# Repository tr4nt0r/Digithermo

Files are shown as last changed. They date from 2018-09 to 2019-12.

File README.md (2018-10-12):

# Digithermo
Digital Thermometer
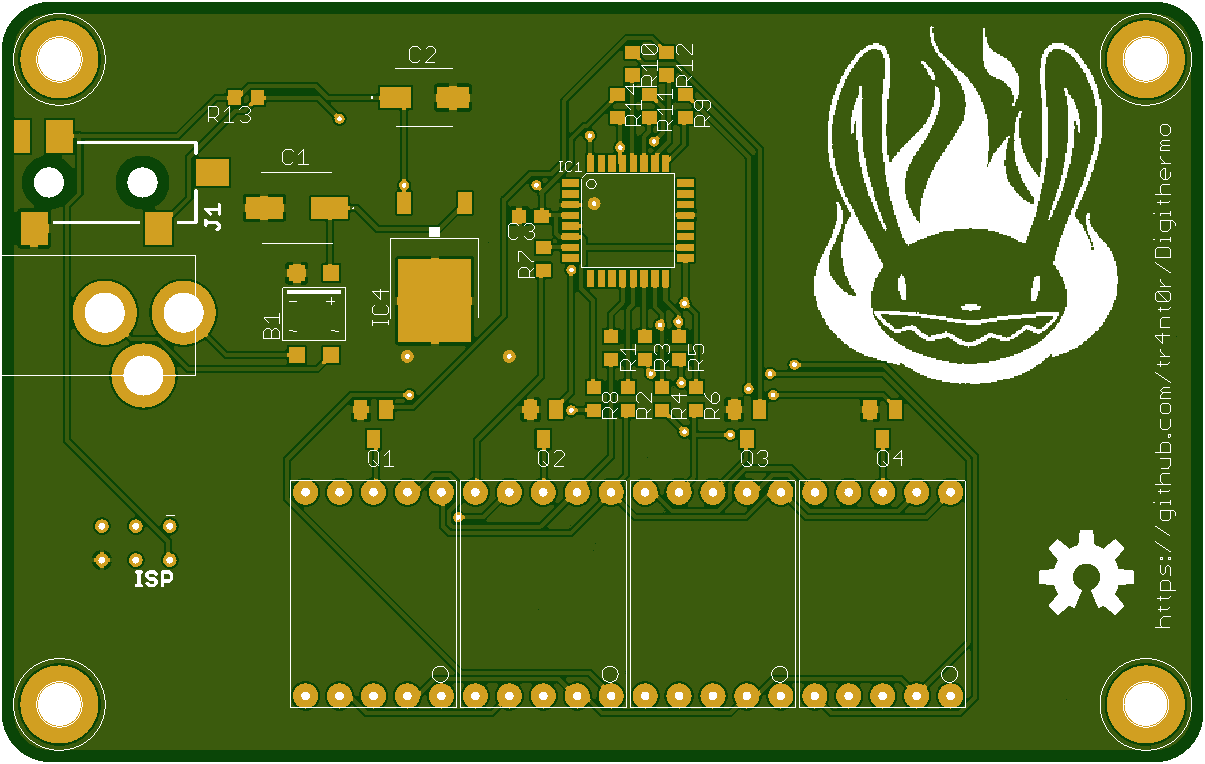
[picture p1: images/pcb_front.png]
PCB Front


# BOM

Qty | Parts              | Value    | Device          | Package      | Description      |Vendor       |
----|--------------------|----------|-----------------|--------------|------------------|-------------|
1   |B1                  |MB6S      |Rectifier        |SOIC-4        |Bridge Rectifier  |[AliExpress](https://www.aliexpress.com/item/-/32838702658.html?spm=a2g0s.8937460.0.0.4f812e0eONVXqt)
1   |C1                  |100µ/16V  |Elko             |SMD 6.3x5.4mm |e.g. EEEFT1C101AR |[AliExpress](https://www.aliexpress.com/item/-/32911815415.html?spm=a2g0s.8937460.0.0.4f812e0eONVXqt)
1   |C2                  |10µ/16V   |Elko             |SMD 5x4mm     |e.g. EEEFK1C100AR |[AliExpress](https://www.aliexpress.com/item/Free-shiping-20pcs-16V-10UF-SMD-4x5mm-chip-Aluminum-Electrolytic-Capacitor/1342839445.html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)
1   |C3                  |100n      |Capacitor        |0603          |
1   |IC1                 |MEGA8     |Microcontroller  |TQFP32        |Atmel ATmega8A-AU|[AliExpress](https://www.aliexpress.com/item/-/32883046023.html?spm=a2g0s.8937460.0.0.4f812e0eONVXqt)
1   |IC4                 |7805      |Voltage regulator|DPAK/TO252    |L78M05CDT        |[AliExpress](https://www.aliexpress.com/item/20pcs-lot-New-78M05-TO252-7805-750mA-L78M05CDT-Three-terminal-voltage-regulator-tube/32818562902.html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)
4   |Q1,Q2,Q3,Q4         |BC847     |Transistor       |SOT23         |NPN Transistor   |[AliExpress](https://www.aliexpress.com/item/100pcs-BC847C-BC847-SOT-23-NPN-smd-transistor/32364894157.html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)
7   |R1,R2,R3,R4,R5,R6,R7|220       |Resistor         |0603          |
1   |R8                  |390       |Resistor         |0603          |
5   |R9,R10,R11,R12,R13  |4,7k      |Resistor         |0603          |
1   |R14                 |10k       |Resistor         |0603          |
4   |U1,U2,U3,U4         |          |7-Segment Display|              |0,56", Common Cathode|[AliExpress](https://www.aliexpress.com/item/-/32876326696.html?spm=a2g0s.8937460.0.0.4f812e0eONVXqt)
1   |J1                  |          |3.5mm Audio Jack |SMD           |e.g. PJ-328          |[AliExpress](https://www.aliexpress.com/item/10PCS-3-5mm-Female-Audio-Connector-5-Pin-SMT-SMD-Headphone-Jack-Socket-PJ-328/32828776775.html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)
1   |                    |          |3.5mm Audio Plug |              |                     |[AliExpress](https://de.aliexpress.com/item/10Pcs-lot-Plastic-metal-3-5mm-Male-Plug-Jack-Adapter-dual-channel-Audio-Connector-Male-Jack/32890263251.html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)
1   |J2                  |          |DC Jack 2.1mm    |              |                     |[AliExpress](https://www.aliexpress.com/item/-/32902679494.html?spm=a2g0s.8937460.0.0.4f812e0eONVXqt)
1   |                    |DS18b20   |Temperaturfühler |              |                     |[AliExpress](https://www.aliexpress.com/item/Stainless-steel-package-Waterproof-DS18b20-temperature-probe-temperature-sensor-18B20-For-Arduino/32236998050.html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)

# Schematic

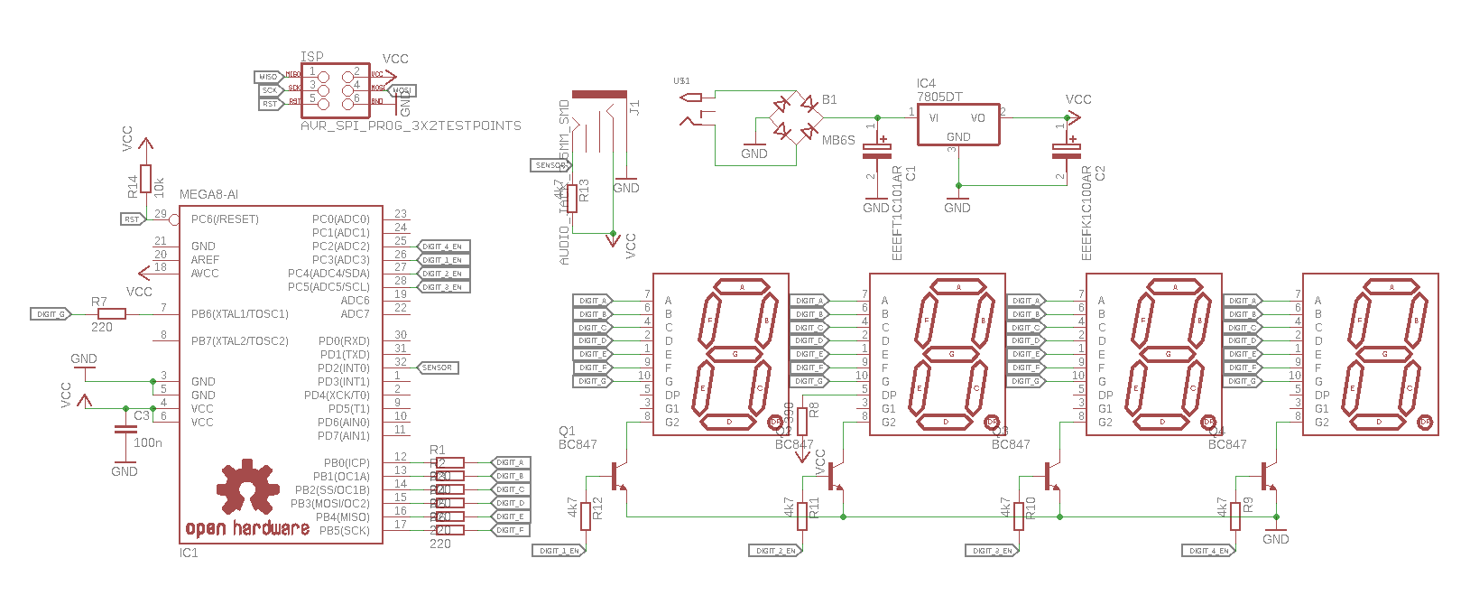
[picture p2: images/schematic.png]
Schematic


# Anschlüsse Temperaturfühler

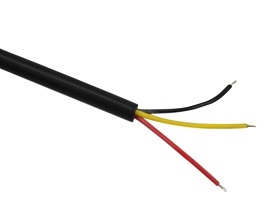
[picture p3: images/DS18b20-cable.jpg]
Anschlüsse Temeperaturfühler


Rot: VCC  
Schwarz: GND  
Gelb: DATA  

# Bilder

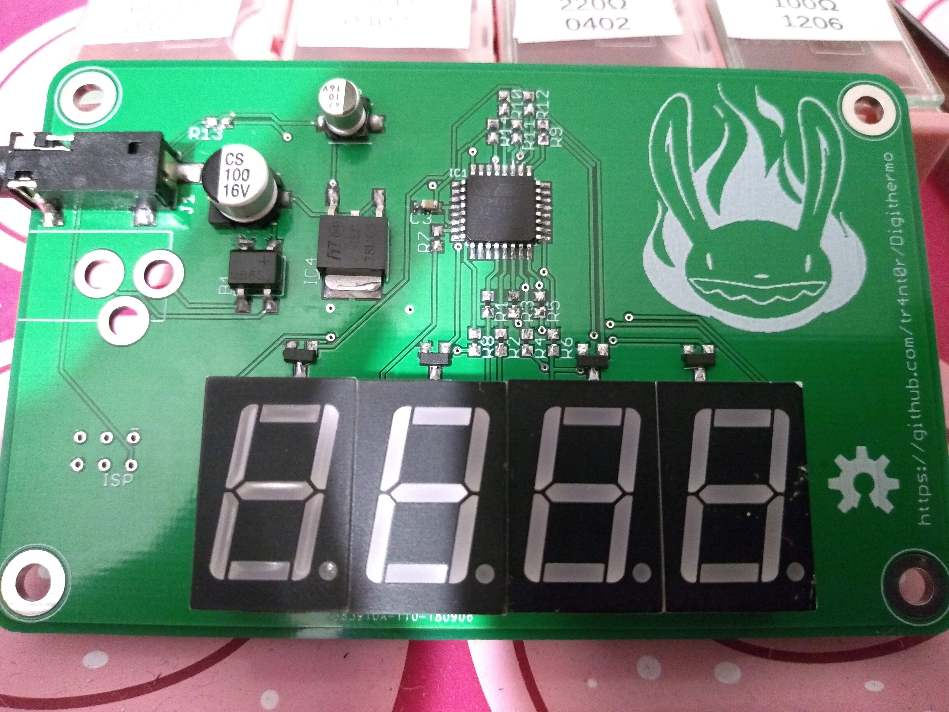
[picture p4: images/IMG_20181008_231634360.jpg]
Bild


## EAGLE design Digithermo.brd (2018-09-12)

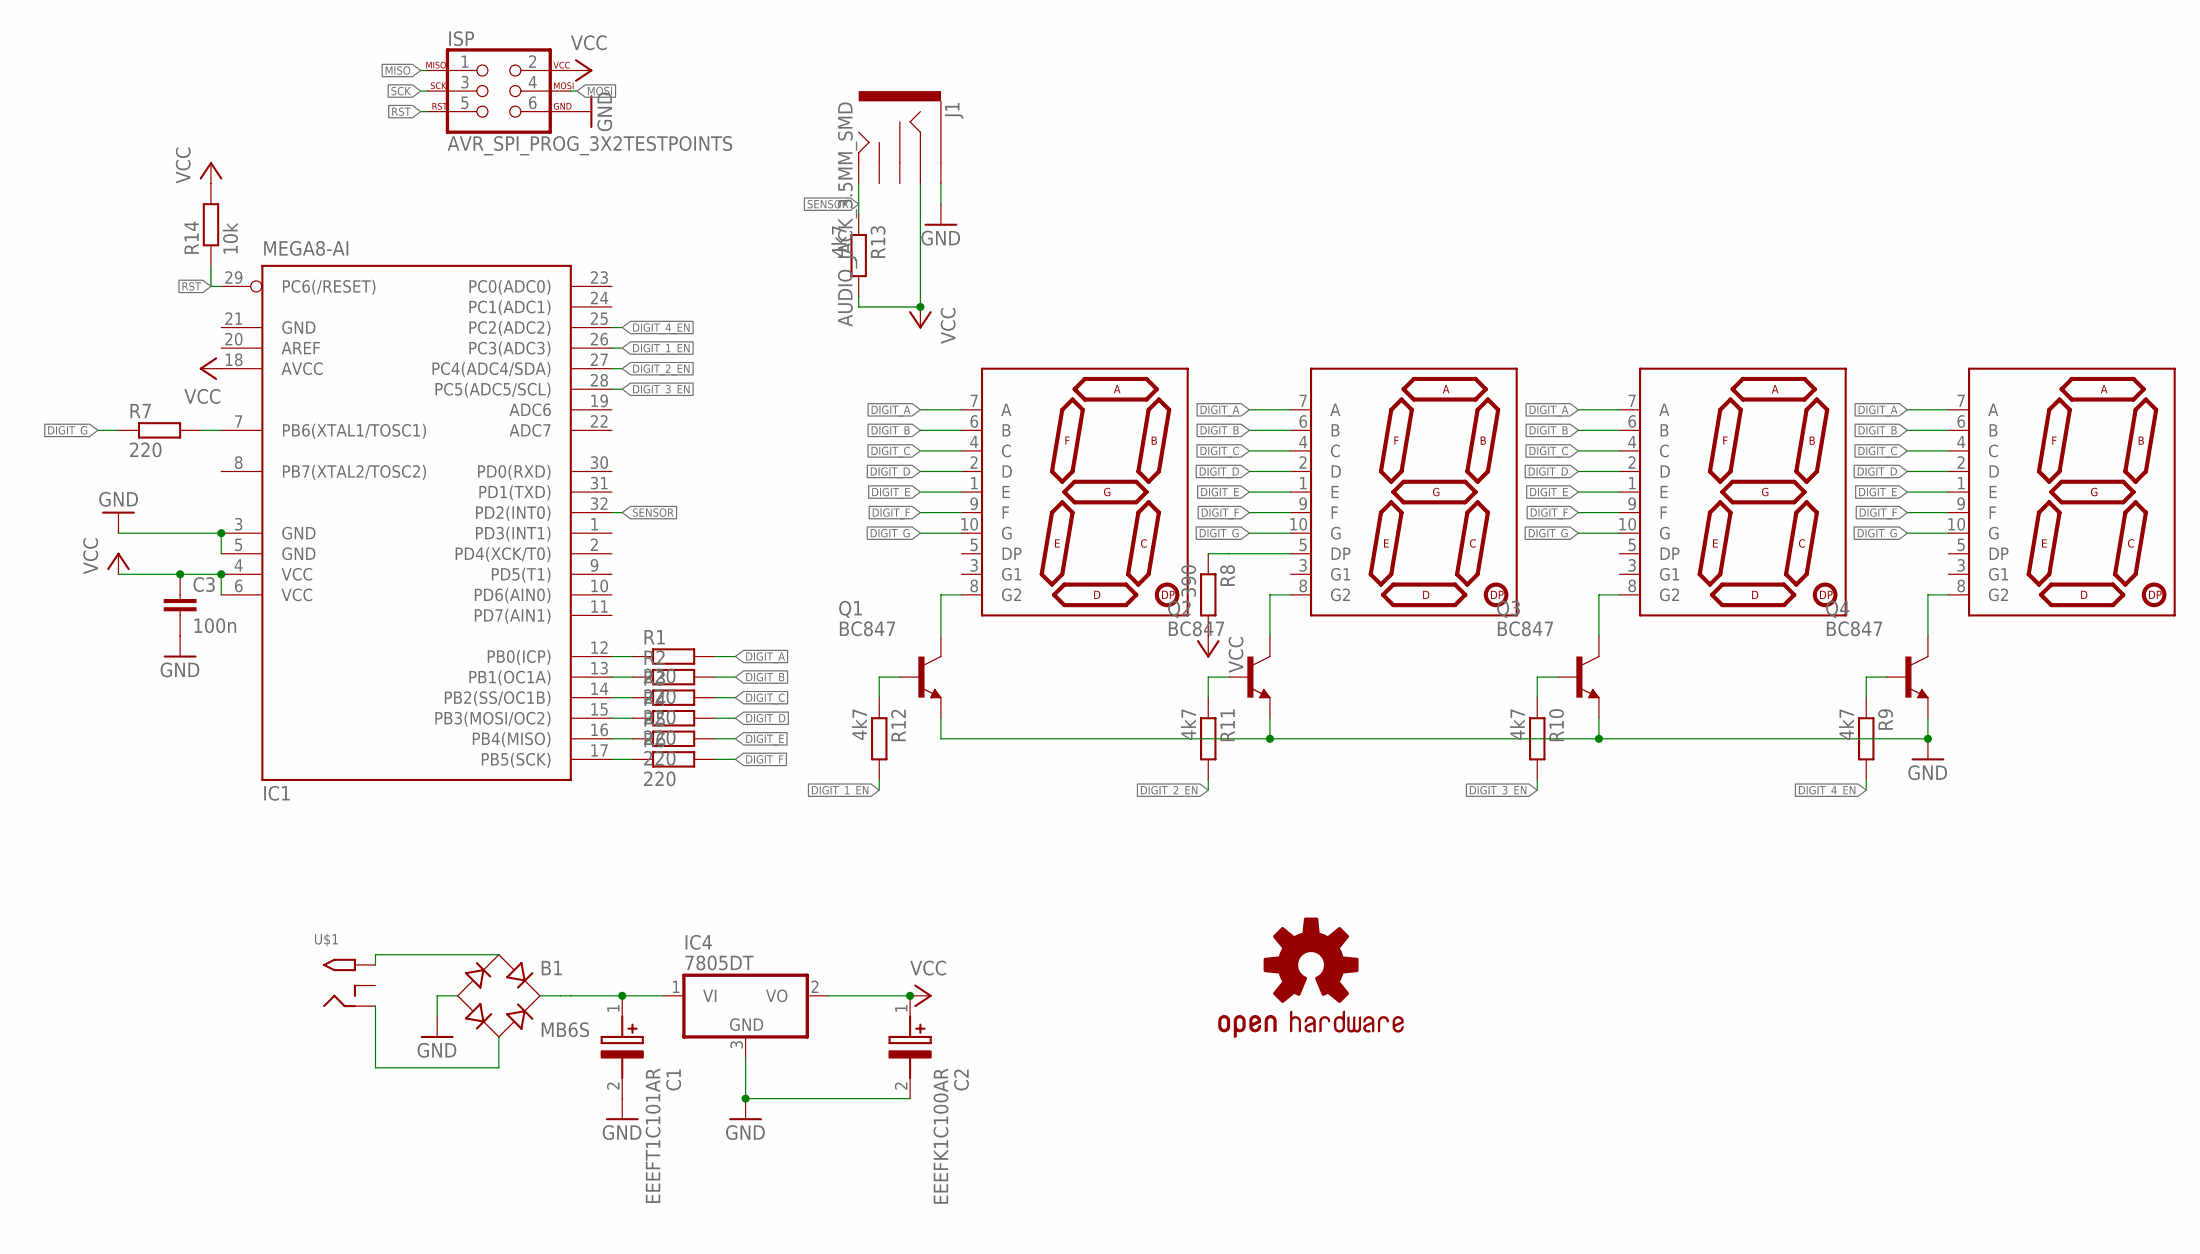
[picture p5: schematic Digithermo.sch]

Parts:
B1: MB6S; SOIC-4
C1: EEEFT1C101AR; HBV(C)
C2: EEEFK1C100AR; FKV(B)
C3: 100n; C0603
IC1: MEGA8-AI; TQFP32-08
IC4: 7805DT; TO252
ISP: AVR_SPI_PROG_3X2TESTPOINTS; 2X3_TEST_POINTS
J1: AUDIO_JACK_3.5MM_SMD; AUDIO-JACK-3.5MM-SMD
LOGO1: OSHW-LOGOL; OSHW-LOGO-L
Q1, Q2, Q3, Q4: BC847; SOT23
R1, R2, R3, R4, R5, R6, R7: 220; R0603
R8: 390; R0603
R9, R10, R11, R12, R13: 4k7; R0603
R14: 10k; R0603
U1, U2, U3, U4: 7-SEGMENT-DISPLAYPTH; 7-SEGMENT-DISPLAY
U$1: 2.1MMJACKTHM; PJ-102A

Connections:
DIGIT_1_EN: IC1.26 (PC3(ADC3)), R12.2
DIGIT_2_EN: IC1.27 (PC4(ADC4/SDA)), R11.2
DIGIT_3_EN: IC1.28 (PC5(ADC5/SCL)), R10.2
DIGIT_4_EN: IC1.25 (PC2(ADC2)), R9.2
DIGIT_A: R1.2, U1.7 (A), U2.7 (A), U3.7 (A), U4.7 (A)
DIGIT_B: R2.2, U1.6 (B), U2.6 (B), U3.6 (B), U4.6 (B)
DIGIT_C: R3.2, U1.4 (C), U2.4 (C), U3.4 (C), U4.4 (C)
DIGIT_D: R4.2, U1.2 (D), U2.2 (D), U3.2 (D), U4.2 (D)
DIGIT_E: R5.2, U1.1 (E), U2.1 (E), U3.1 (E), U4.1 (E)
DIGIT_F: R6.2, U1.9 (F), U2.9 (F), U3.9 (F), U4.9 (F)
DIGIT_G: R7.1, U1.10 (G), U2.10 (G), U3.10 (G), U4.10 (G)
GND: B1.-, C1.2 (-), C2.2 (-), C3.2, IC1.3 (GND), IC1.5 (GND), IC1.21 (GND), IC4.3 (GND), ISP.6, J1.SLEEVE, Q1.2 (E), Q2.2 (E), Q3.2 (E), Q4.2 (E)
MISO: IC1.16 (PB4(MISO)), ISP.1, R5.1
MOSI: IC1.15 (PB3(MOSI/OC2)), ISP.4, R4.1
unnamed: B1.~1 (AC1), U$1.TIP
unnamed: B1.~2 (AC2), U$1.RING
unnamed: B1.+, C1.1 (+), IC4.1 (VI)
unnamed: IC1.7 (PB6(XTAL1/TOSC1)), R7.2
unnamed: Q1.3 (C), U1.8 (G2)
unnamed: R8.1, U2.5 (DP)
unnamed: IC1.14 (PB2(SS/OC1B)), R3.1
unnamed: IC1.13 (PB1(OC1A)), R2.1
unnamed: IC1.12 (PB0(ICP)), R1.1
unnamed: Q1.1 (B), R12.1
unnamed: Q2.3 (C), U2.8 (G2)
unnamed: Q2.1 (B), R11.1
unnamed: Q3.3 (C), U3.8 (G2)
unnamed: Q3.1 (B), R10.1
unnamed: Q4.3 (C), U4.8 (G2)
unnamed: Q4.1 (B), R9.1
RST: IC1.29 (PC6(/RESET)), ISP.5, R14.1
SCK: IC1.17 (PB5(SCK)), ISP.3, R6.1
SENSOR: IC1.32 (PD2(INT0)), J1.TIP, R13.1
VCC: C2.1 (+), C3.1, IC1.4 (VCC), IC1.6 (VCC), IC1.18 (AVCC), IC4.2 (VO), ISP.2, J1.RING, R8.2, R13.2, R14.2

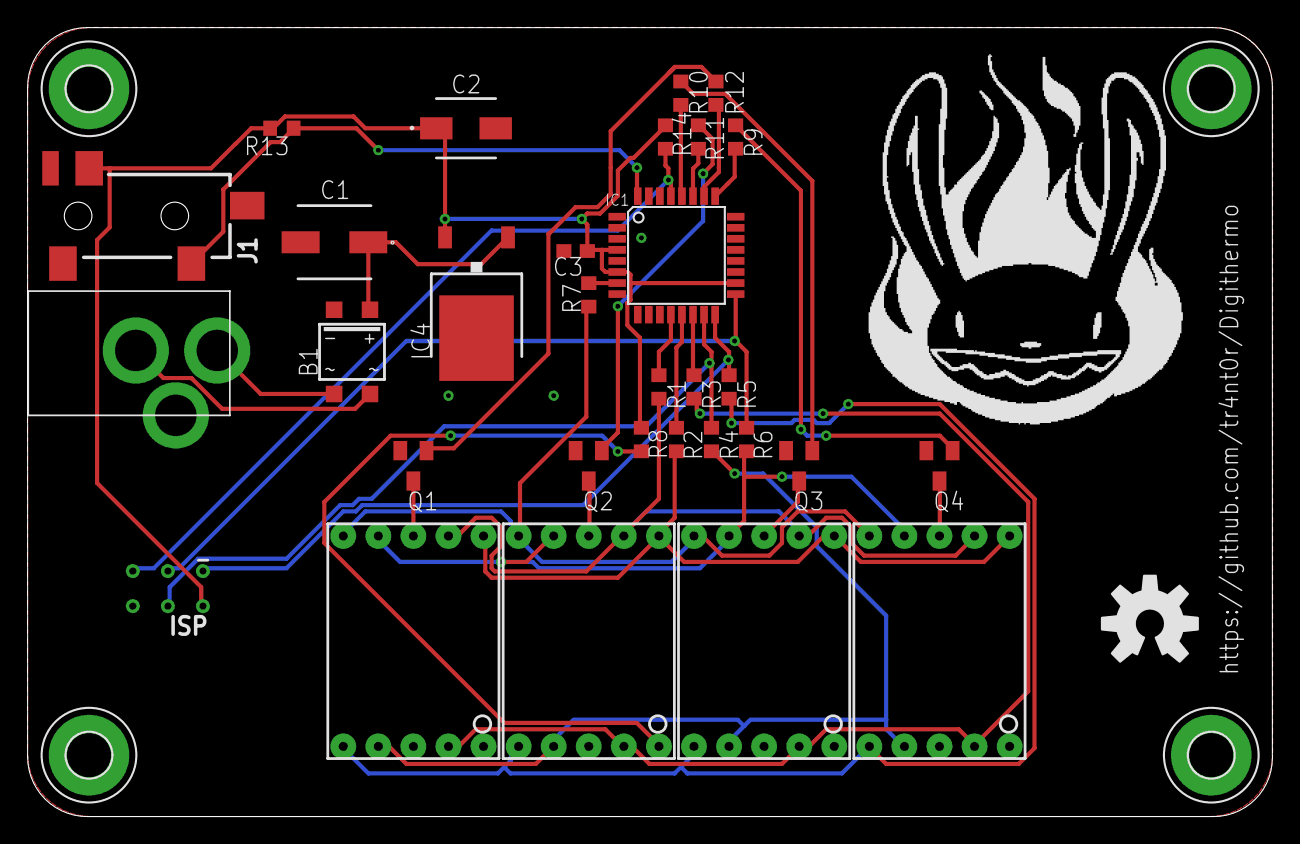
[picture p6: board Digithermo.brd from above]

Board: 2 copper layers, 90.2 x 57.1 mm, 36 parts (0 on the bottom side), 34 nets.

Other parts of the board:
E$1, E$2, E$3, E$4: 3,2-PAD

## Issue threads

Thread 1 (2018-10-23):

Dezimalpunkt an falscher Stelle

tr4nt0r, 2018-10-23:
Dezimalpunkt hätte eine Stelle weiter rechts sein müssen, damit die vom Sensor messbaren Temperaturen
bis 120°C mit 3 Stellen und bei negativen Temperaturen bis -50° das Vorzeichen dargestellt werden können.
Zwei Nachkommastellen sind nicht erforderlich, da die Sensorgenauigkeit bei 0,5°C liegt.

tr4nt0r, 2018-10-24:
Related 6be8a3d217f9e89993d3480dadc9c6d718803c93

Closed 2024-04-27.

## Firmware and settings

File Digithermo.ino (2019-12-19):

// Beware of bugs in the code; I have only proved it correct, not tried it.

#include <TimerOne.h>
#include <DallasTemperature.h>
#include <OneWire.h>

const uint8_t numbers[10] = { 0x3F, 0x06, 0x5B, 0x4F, 0x66, 0x6D, 0x7D, 0x07, 0x7F, 0x6f };
const uint8_t letter_E = 0x79;
const uint8_t letter_r = 0x50;
const uint8_t symbol_minus = 0x40;

const uint8_t digit2pin[4] = { 16, 19, 18, 17 };
const uint8_t SENSOR_PIN = 2;
uint8_t active = 0;
uint8_t digit = 0;
volatile int16_t temperature;
volatile bool sensorError = false;

OneWire wire(SENSOR_PIN);
DallasTemperature sensors(&wire);

void setup()
{
	DDRB = 0xFF; //set PB0 - PB6 as Output
	DDRC = 0xFF; //set PC2 - PC5 as Output

	Timer1.initialize(5000);
	Timer1.attachInterrupt(displayMultiplex);	
	selftest();
	sensors.begin();
}

void loop()
{
	//wait for sensor to connect
	while (!sensors.requestTemperaturesByIndex(0)) {
		sensorError = true;
		delay(1000);
	}
	sensorError = false;
	noInterrupts();
	temperature = (int16_t)(sensors.getTempCByIndex(0) * 10.0);
	interrupts();
	delay(1000);
}

void selftest() {
	//7-segment display selftest
	uint8_t i = 10;
	while (i-- > 0) {
		temperature = 1111 * i;
		delay(50000);
	}
}


void displayMultiplex() {
	digitalWrite(digit2pin[active], LOW);  //disable last digit
	active = (active == 3) ? 0 : active + 1; //go to next digit
	digitalWrite(digit2pin[active], HIGH); //enable next digit
	PORTB = 0;
	if (!sensorError) {

		if (temperature < 0 && active == 3) {
			PORTB = symbol_minus;
		}
		else if (abs(temperature) < pow(10, active) && active > 1){  //don't display leading zero
			PORTB = 0;
		} else {
			digit = abs(temperature) / pow(10, active) % 10;  //get number to display on active digit
			PORTB = numbers[digit];  //Set I/Os for digit
		}
	} else {
		//display Err 
		switch (active) {
		case 0:
			PORTB = 0x00; //Digit off			
			break;
		case 3:
			PORTB = letter_E;
			break;
		case 2:
		case 1:
			PORTB = letter_r;
			break;
		}
	}
}

int32_t pow(int base, int exp) {
	int32_t result = 1;
	for (;;) {
		if (exp & 1)
			result *= base;
		exp >>= 1;
		if (!exp)
			break;
		base *= base;
	}

	return result;
}

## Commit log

2018-09-09 added image of pcb front
2018-09-09 Added BOM to README.md
2018-09-12 Eckenrundungen geändert
    [Digithermo.brd]
2018-09-12 added schematic image
2018-09-26 First commit of firmware
    Beware of bugs in the code; I have only proved it correct, not tried it!
    [Digithermo.ino]

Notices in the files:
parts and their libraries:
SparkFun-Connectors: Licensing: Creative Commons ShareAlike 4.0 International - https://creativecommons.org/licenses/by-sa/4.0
